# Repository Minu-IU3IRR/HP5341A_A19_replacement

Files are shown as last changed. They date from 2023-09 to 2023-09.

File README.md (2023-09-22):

# HP5341A_A19_replacement

A project for restoring old HP5341A frequency counters.

this repo contains the Arduino sketch that enables full control over the intrument, even via Serial port usign standard VISA commands. if you wish to use the Arduno mega you will find the kicad project for the shield that allows easy connection of the wires on the mainboard and socket for the original display.
if you wish to use another board make shure that 5v can be handeled, all the logic on the instrument is 5V.

supported commands:
*IDN?    ->   standard ICSP command

:FREQ?   ->   last valid reading or zero.

:BAND?   ->   witch IF band the istrument is operating on.

:RES?    ->   the current resolution setted on the counter, expressed as the esponent of 10, example 2 => 10^2 Hz.

:DEAD?   ->   returns 1 if the instrument is in deadtime from gating, else retruns 0.

:GATE?   ->   returns 1 if the GATE is open, else returns false.

:STAT?   ->   returns a string representing the status of the instrument in human readable form to bedug.

-VERY IMPORTANT!
if you supply power to the arduino with the shield make shure to disconnect the 5V positive wire from the USB port so you will not connect your computer's 5V bus to the insturment one, BAD things can occur. the ground wire must remain connected. to supply the arduino from your PC just avoid soldering the +5V pins on the shield and the voltages are separated, keep in mind that the instrument must supply the display if original, it can pull up to 1A that the arduno or PC can not provide.

Feel free to reproduce all the content, just make shure to link this repo as the source!

under any circumstance i will take ANY responsability for damage of any kind to anything or anyone from reproducing any part of the cntents of this repo.....

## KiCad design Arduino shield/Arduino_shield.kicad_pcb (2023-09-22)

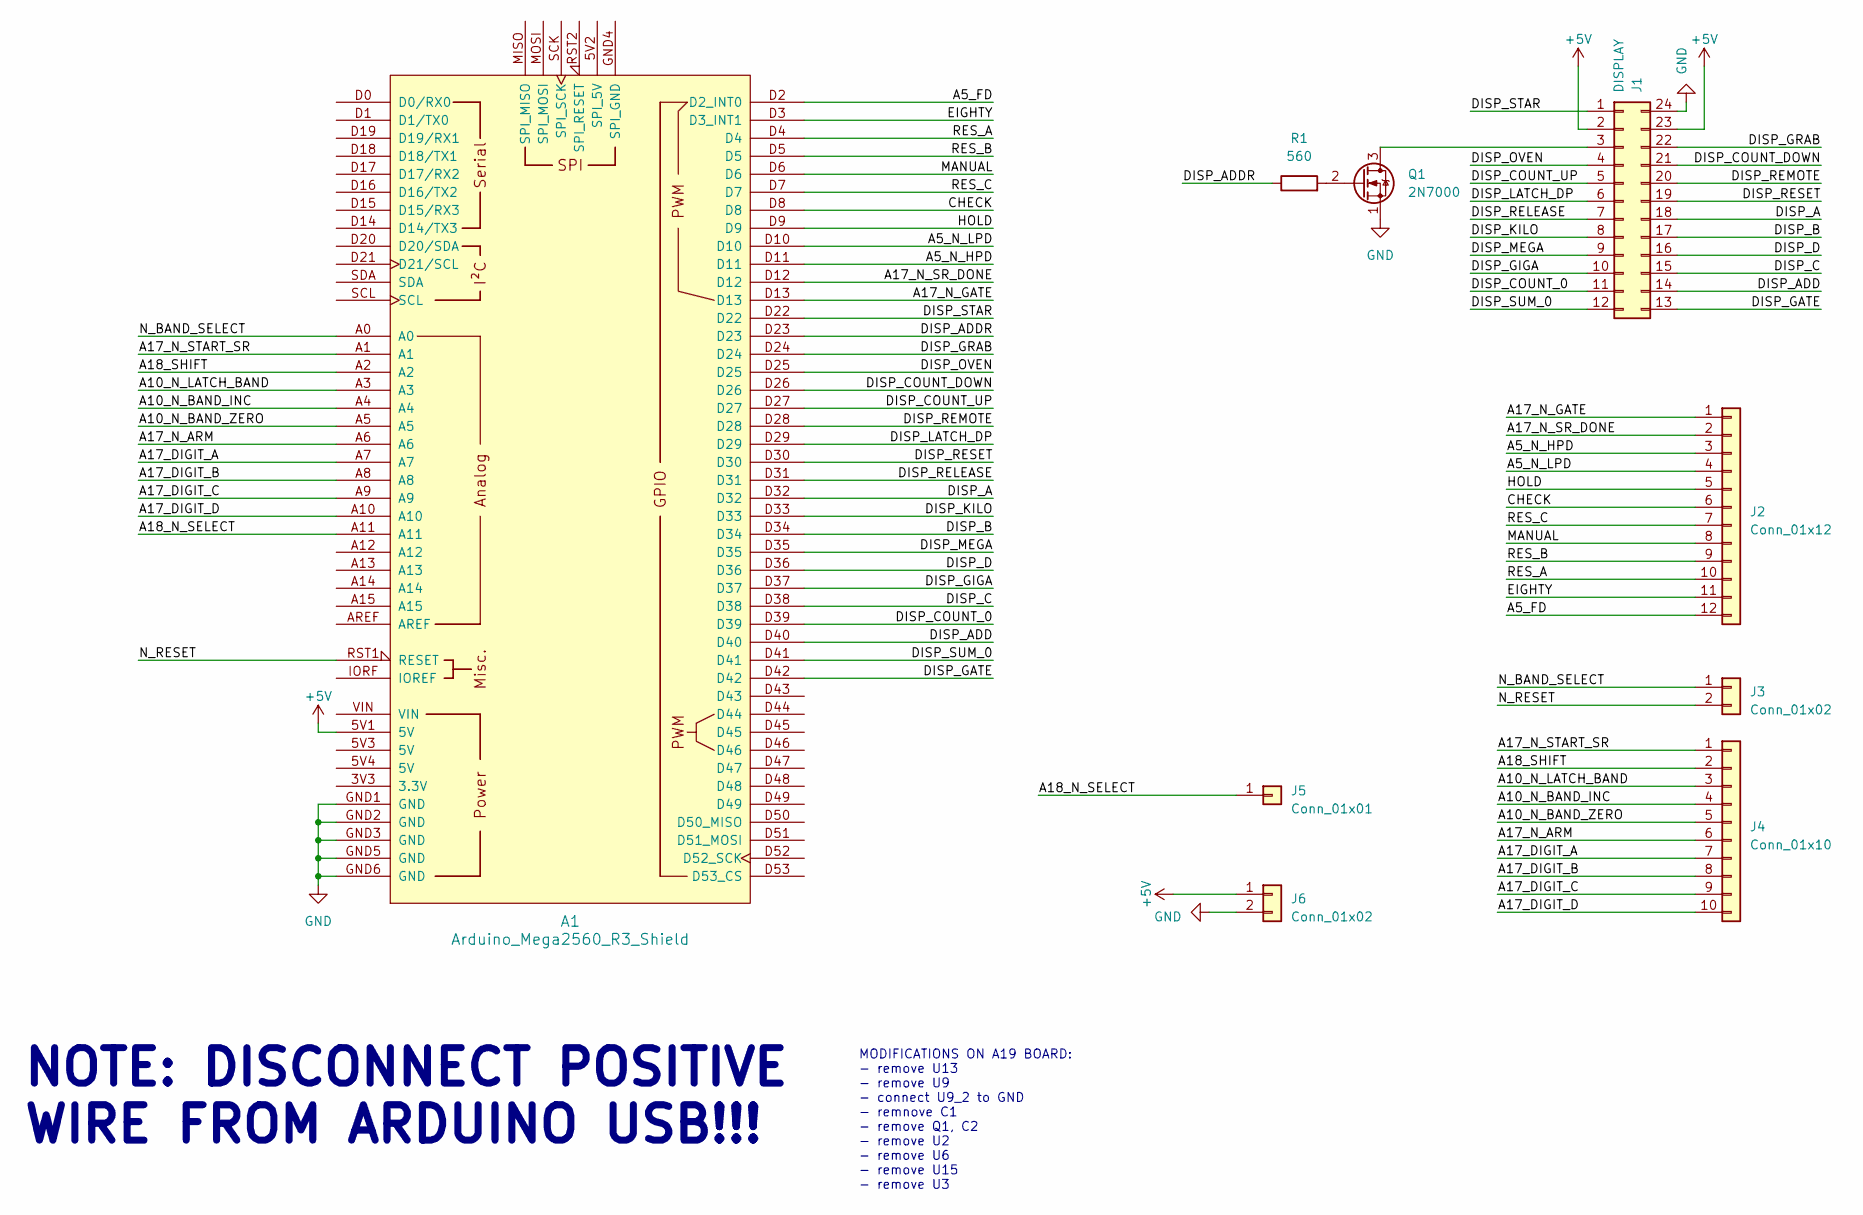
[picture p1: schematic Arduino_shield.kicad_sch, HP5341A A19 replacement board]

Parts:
A1: Arduino_Mega2560_R3_Shield
J1: DISPLAY; DIP-24_W15.24mm_Socket
J2: Conn_01x12; PinHeader_1x12_P2.54mm_Vertical
J3, J6: Conn_01x02; PinHeader_1x02_P2.54mm_Vertical
J4: Conn_01x10; PinHeader_1x10_P2.54mm_Vertical
J5: Conn_01x01; PinHeader_1x01_P2.54mm_Vertical
Q1: 2N7000; TO-92_Inline
R1: 560; R_Axial_DIN0207_L6.3mm_D2.5mm_P10.16mm_Horizontal

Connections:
+5V: A1.5V1 (5V), J1.2, J1.23, J6.1
/A5_FD: A1.D2 (D2_INT0), J2.12
/A5_N_HPD: A1.D11, J2.3
/A5_N_LPD: A1.D10, J2.4
/A10_N_BAND_INC: A1.A4, J4.4
/A10_N_BAND_ZERO: A1.A5, J4.5
/A10_N_LATCH_BAND: A1.A3, J4.3
/A17_DIGIT_A: A1.A7, J4.7
/A17_DIGIT_B: A1.A8, J4.8
/A17_DIGIT_C: A1.A9, J4.9
/A17_DIGIT_D: A1.A10, J4.10
/A17_N_ARM: A1.A6, J4.6
/A17_N_GATE: A1.D13, J2.1
/A17_N_SR_DONE: A1.D12, J2.2
/A17_N_START_SR: A1.A1, J4.1
/A18_N_SELECT: A1.A11, J5.1
/A18_SHIFT: A1.A2, J4.2
/CHECK: A1.D8, J2.6
/DISP_A: A1.D32, J1.18
/DISP_ADD: A1.D40, J1.14
/DISP_ADDR: A1.D23, R1.1
/DISP_B: A1.D34, J1.17
/DISP_C: A1.D38, J1.15
/DISP_COUNT_0: A1.D39, J1.11
/DISP_COUNT_DOWN: A1.D26, J1.21
/DISP_COUNT_UP: A1.D27, J1.5
/DISP_D: A1.D36, J1.16
/DISP_GATE: A1.D42, J1.13
/DISP_GIGA: A1.D37, J1.10
/DISP_GRAB: A1.D24, J1.22
/DISP_KILO: A1.D33, J1.8
/DISP_LATCH_DP: A1.D29, J1.6
/DISP_MEGA: A1.D35, J1.9
/DISP_OVEN: A1.D25, J1.4
/DISP_RELEASE: A1.D31, J1.7
/DISP_REMOTE: A1.D28, J1.20
/DISP_RESET: A1.D30, J1.19
/DISP_STAR: A1.D22, J1.1
/DISP_SUM_0: A1.D41, J1.12
/EIGHTY: A1.D3 (D3_INT1), J2.11
/HOLD: A1.D9, J2.5
/MANUAL: A1.D6, J2.8
/N_BAND_SELECT: A1.A0, J3.1
/N_RESET: A1.RST1 (RESET), J3.2
/RES_A: A1.D4, J2.10
/RES_B: A1.D5, J2.9
/RES_C: A1.D7, J2.7
GND: A1.GND1 (GND), A1.GND2 (GND), A1.GND3 (GND), A1.GND5 (GND), A1.GND6 (GND), J1.24, J6.2, Q1.1 (S)
unnamed: J1.3, Q1.3 (D)
unnamed: Q1.2 (G), R1.2

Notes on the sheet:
MODIFICATIONS ON A19 BOARD: - remove U13 - remove U9 - connect U9_2 to GND - remnove C1 - remove Q1, C2 - remove U2 - remove U6 - remove U15 - remove U3
NOTE: DISCONNECT POSITIVE WIRE FROM ARDUINO USB!!!

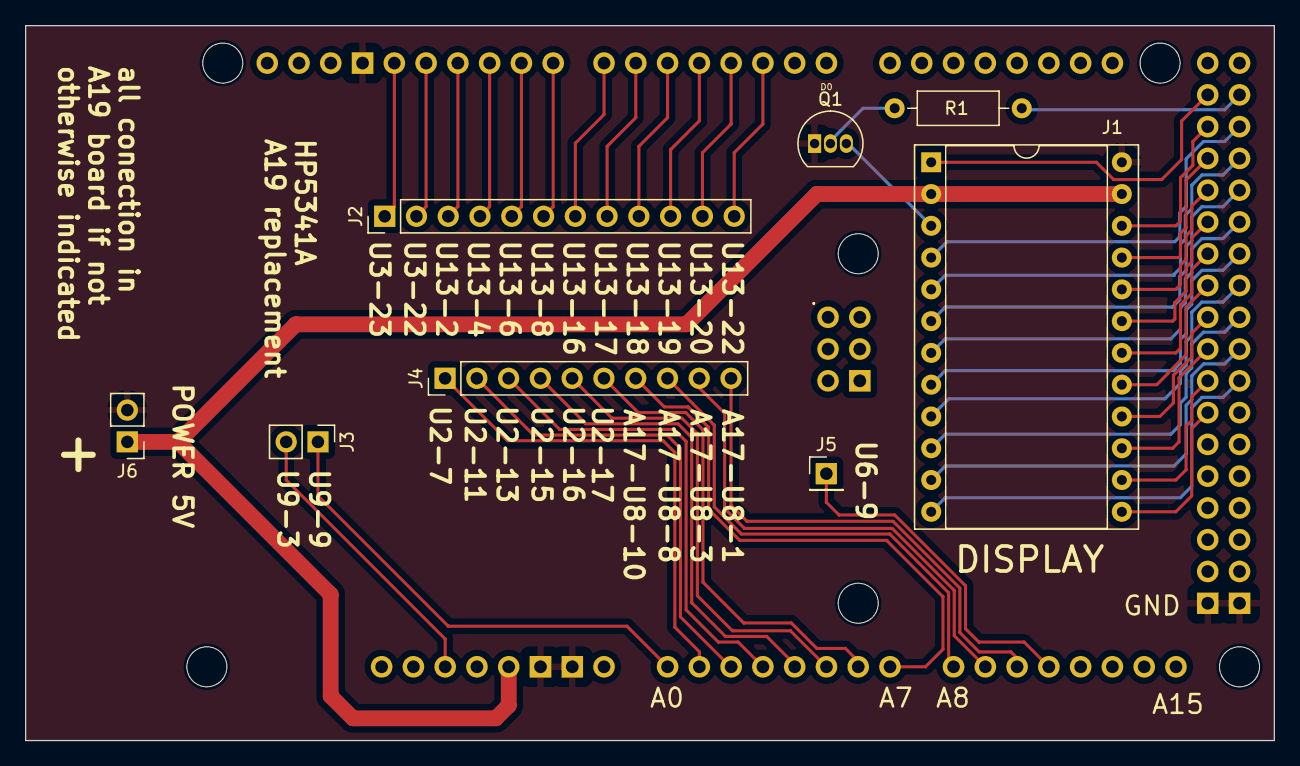
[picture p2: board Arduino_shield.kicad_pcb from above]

Board: 2 copper layers, 99.8 x 57.1 mm, 9 parts (0 on the bottom side), 50 nets.

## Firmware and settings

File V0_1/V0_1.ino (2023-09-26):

#include "IF.h"
#include "band_filter.h"
#include "display.h"
#include "counter.h"
#include "front_panel.h"
#include "timing.h"
#include "VISA.h"

#define IDN "HP,5341A,ArduinoVisa,FW0.1"
unsigned long baud_rate = 115200;

VISA interface = VISA(baud_rate);

BoardA5 IF = BoardA5();
BoardA10 filter = BoardA10();
BoardA15 display = BoardA15();
BoardA17 timing = BoardA17();
BoardA18 counter = BoardA18();
BoardA19 front_panel = BoardA19();


bool update = false;  // becomes true if ay parameter has changed = reset
bool waiting_deadtime = false;
bool valid_high_band_signal = false;

int resolution = 0;
bool high_range = 0;
bool band_auto = false;

uint64_t last_reading = 0;


#define BAND_COUNT 9
uint64_t band_offset[7][10] = {
  { 0, 500000000, 750000000, 1000000000, 1500000000, 2000000000, 2500000000, 3000000000, 3500000000, 4000000000 },
  { 0, 50000000, 75000000, 100000000, 150000000, 200000000, 250000000, 300000000, 350000000, 400000000 },
  { 0, 5000000, 7500000, 10000000, 15000000, 20000000, 25000000, 30000000, 35000000, 40000000 },
  { 0, 500000, 750000, 1000000, 1500000, 2000000, 2500000, 3000000, 3500000, 4000000 },
  { 0, 50000, 75000, 100000, 150000, 200000, 250000, 300000, 350000, 400000 },
  { 0, 5000, 7500, 10000, 15000, 20000, 25000, 30000, 35000, 40000 },
  { 0, 500, 750, 1000, 1500, 2000, 2500, 3000, 3500, 4000 },
};


void setup() {

  interface.open();

  IF.init();
  filter.init();
  display.init();
  counter.init();
  front_panel.init();
  timing.init();

  update = true;
}

void loop() {

  //---------------------------------------------------------------remote control
  if (Serial.available() > 0) {
    String serial_input = Serial.readStringUntil('\n');
    serial_input.trim();  // remove \n at end of string

    String command;
    String argument;

    bool is_scpi = interface.parse_scpi(serial_input, command);
    if (is_scpi) {
      if (command == "*IDN?") {
        interface.write(IDN);
      } else {
        interface.error(1, "invalid VISA command");
      }
    }
    bool is_visa = interface.parse_visa(serial_input, command, argument);
    if (is_visa) {
      //valid command
      if (argument == "FREQ?") {
        String frequeuncy_sring = uint64ToString(last_reading);
        for (int i = 0; i < resolution; i++) {
          frequeuncy_sring += "0";
        }
        interface.write(frequeuncy_sring);
      } else if (argument == "BAND?") {
        interface.write(String(filter.band));
      } else if (argument == "RES?") {
        interface.write(String(resolution));
      } else if (argument == "DEAD?") {
        interface.write(String(int(waiting_deadtime)));
      } else if (argument == "GATE?") {
        interface.write(String(int(!waiting_deadtime)));
      } else if (argument == "STAT?") {
        interface.write(status_string());
      } else {
        interface.error(2, "invalid VISA command");
      }
    }
  }

  //---------------------------------------------------------------update enviroment

  check_change(front_panel.resolution(), &resolution, &update);
  check_change(front_panel.input_high_range(), &high_range, &update);
  check_change(front_panel.band_automatic(), &band_auto, &update);

  //---------------------------------------------------------------range management
  if (high_range) {
    if (IF.is_low_level()) {  // display
      display.light_star_pulse();
    }

    if (band_auto) {
      valid_high_band_signal = IF.in_band() && IF.is_high_level();
      if (!valid_high_band_signal) {
        for (int band = 0; band <= BAND_COUNT; band++) {
          filter.set(band);
          delay(1);
          if (IF.in_band() && !IF.is_low_level()) {
            update = true;
            break;
          }
        }
      }
    } else {
      valid_high_band_signal = IF.in_band();
      if (front_panel.band_button_pressed()) {
        delay(300);  //debounce

        int new_band = filter.band + 1;
        if (new_band > BAND_COUNT) {  // rollover
          new_band = 0;
        }
        //Serial.println("manual band selection : " + String(current_band));
        filter.set(new_band);
        update = true;
      }
    }
  } else if (front_panel.input_check()) {
    filter.set(1);  // set fixed band
  } else {
    //band eighty
  }

  //--------------------------------------------------------------- update
  if (update) {
    update = false;
    waiting_deadtime = false;
    last_reading = 0;

    display.reset();
    timing.arm();

    // display_update
    if (resolution < 3) {
      display.light_kilo();
    } else if (resolution < 6) {
      display.light_mega();
    } else {
      display.light_giga();
    }

    int decimal_position = 3 - (resolution % 3);
    display.decimal_position(decimal_position);
  }

  // ------------------------------------------------------------- gating
  if (timing.gate_state()) {
    display.light_gate_pulse();
  } else {
    if (!waiting_deadtime) {
      timing.start_deadtime();
      waiting_deadtime = true;

      uint64_t reading = counter.read();

      if (high_range) {

        //println64(&Serial, reading);
        //println64(&Serial, band_offset[resolution][current_band]);
        if (valid_high_band_signal) {
          if (!front_panel.input_check()) {
            reading = reading + band_offset[resolution][filter.band];
          }
        } else {
          reading = 0;
        }
      }
      display.print(reading);
      last_reading = reading;
      //println64(&Serial, reading);
    }
  }
  if (waiting_deadtime) {
    if (timing.deadtime_expired()) {
      waiting_deadtime = false;
      timing.arm();
    }
  }
}

template<typename T>
void check_change(T current_value, T* old_value, bool* change_detected) {
  if (current_value != *old_value) {
    *old_value = current_value;
    *change_detected = true;
  }
}

String uint64ToString(uint64_t input) {
  String result = "";
  uint8_t base = 10;

  do {
    char c = input % base;
    input /= base;

    if (c < 10)
      c +='0';
    else
      c += 'A' - 10;
    result = c + result;
  } while (input);
  return result;
}

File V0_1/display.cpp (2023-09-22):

#include "display.h"

BoardA15::BoardA15() {
}

void BoardA15::init() {
  pinMode(pin_Addr, OUTPUT);
  pinMode(pin_STAR, OUTPUT);
  pinMode(pin_OVEN, OUTPUT);
  pinMode(pin_REMOTE, OUTPUT);
  pinMode(pin_KILO, OUTPUT);
  pinMode(pin_MEGA, OUTPUT);
  pinMode(pin_GIGA, OUTPUT);
  pinMode(pin_GATE, OUTPUT);
  pinMode(pin_RELEASE, OUTPUT);
  pinMode(pin_GRAB, OUTPUT);
  pinMode(pin_CU, OUTPUT);
  pinMode(pin_CD, OUTPUT);
  pinMode(pin_LATCH_DP, OUTPUT);
  pinMode(pin_ADD, OUTPUT);
  pinMode(pin_RELEASE, OUTPUT);
  pinMode(pin_RESET, OUTPUT);
  pinMode(pin_A, OUTPUT);
  pinMode(pin_B, OUTPUT);
  pinMode(pin_C, OUTPUT);
  pinMode(pin_D, OUTPUT);

  digitalWrite(pin_STAR, HIGH);
  digitalWrite(pin_GATE, HIGH);

  //multiplexer init
  counter_state(true);

  digitalWrite(pin_CU, HIGH);
  digitalWrite(pin_CD, HIGH);
  digitalWrite(pin_LATCH_DP, HIGH);
  digitalWrite(pin_RELEASE, HIGH);
  digitalWrite(pin_RESET, HIGH);
  digitalWrite(pin_A, HIGH);
  digitalWrite(pin_B, HIGH);
  digitalWrite(pin_C, HIGH);
  digitalWrite(pin_D, HIGH);

  light_addr(false);
  light_oven(false);
  light_rmt(false);
  light_kilo();

  // ram write disable
  ram_write_enable(false);
}

void BoardA15::light_addr(bool state) {
  digitalWrite(pin_Addr, state);
}

void BoardA15::light_kilo() {
  digitalWrite(pin_KILO, LOW);
  digitalWrite(pin_MEGA, HIGH);
  digitalWrite(pin_GIGA, HIGH);
}
void BoardA15::light_mega() {
  digitalWrite(pin_KILO, HIGH);
  digitalWrite(pin_MEGA, LOW);
  digitalWrite(pin_GIGA, HIGH);
}
void BoardA15::light_giga() {
  digitalWrite(pin_KILO, HIGH);
  digitalWrite(pin_MEGA, HIGH);
  digitalWrite(pin_GIGA, LOW);
}
void BoardA15::light_gate_pulse() {
  digitalWrite(pin_GATE, LOW);
  delayMicroseconds(3);
  digitalWrite(pin_GATE, HIGH);
}
void BoardA15::light_oven(bool state) {
  digitalWrite(pin_OVEN, state);
}
void BoardA15::light_star_pulse() {
  digitalWrite(pin_STAR, LOW);
  delayMicroseconds(3);
  digitalWrite(pin_STAR, HIGH);
}
void BoardA15::light_rmt(bool state) {
  digitalWrite(pin_REMOTE, !state);
}
void BoardA15::reset() {
  digitalWrite(pin_RESET, LOW);
  delayMicroseconds(10);
  digitalWrite(pin_RESET, HIGH);

  print(0);
  decimal_position(0);
  light_oven(false);
  light_rmt(false);
}
void BoardA15::print(uint64_t number) {
  //stop counter and reset addr
  counter_state(false);
  ram_write_enable(true);

  //println64(&Serial, number);

  for (int i = 0; i < DISPLAY_DIGITS; i++) {
    // Extract the last digit
    uint8_t digit = number % 10;

    // Convert the decimal digit to BCD
    uint8_t bcd = (digit / 10) << 4 | (digit % 10);

    //--------------------------------------------------------------
    // if residual number == 0 -> remove leading zeros pointing to BCD 15
    if (number == 0 && i > 0) {
      bcd = 15;
    }

    // Remove the last digit from the number
    number /= 10;

    // Invert all bits of the BCD value
    bcd = ~bcd;

    // Send the BCD value to the pins
    for (int j = 0; j < 4; j++) {
      // Set the BCD pins based on the bits of bcd
      digitalWrite(bds_pins[j], (bcd >> j) & 1);
    }

    // Pulse the count_up only if not last digit
    if (i != (DISPLAY_DIGITS - 1)) {
      counter_increment();
    }
    delayMicroseconds(10);  // Adjust this delay as needed
  }


  ram_write_enable(false);
  counter_state(true);
}

void BoardA15::decimal_position(int position) {
  counter_state(false);
  for (int i = 0; i < DISPLAY_DIGITS; i++) {
    if (i == position) {
      digitalWrite(pin_LATCH_DP, LOW);
      delayMicroseconds(10);
      digitalWrite(pin_LATCH_DP, HIGH);
      break;
    }
    counter_increment();
  }
  counter_state(true);
}

//********************************************private

void BoardA15::ram_write_enable(bool state) {
  digitalWrite(pin_ADD, !state);
  delayMicroseconds(10);
}
void BoardA15::counter_increment() {
  digitalWrite(pin_CU, LOW);
  delayMicroseconds(10);  // Adjust this delay as needed
  digitalWrite(pin_CU, HIGH);
}

void BoardA15::counter_state(bool en) {
  int a_pin = pin_RELEASE;  // release oscillator
  int b_pin = pin_GRAB;     //latch gate to grab zero in memory
  if (en) {
    a_pin = pin_GRAB;
    b_pin = pin_RELEASE;
  }
  digitalWrite(a_pin, HIGH);
  digitalWrite(b_pin, LOW);
  delayMicroseconds(10);
  digitalWrite(b_pin, HIGH);
}

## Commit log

2023-09-22 Add files via upload
    first commit
    [Arduino_shield.kicad_pcb, Arduino_shield.kicad_sch]
2023-09-26 Update V0_1.ino
    bug fix in decimal point position
    [V0_1.ino]
